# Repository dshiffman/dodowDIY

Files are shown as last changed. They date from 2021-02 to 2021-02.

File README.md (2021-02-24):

# dodowDIY
**An ATTiny85 implementation of the well known sleep aid. Includes circuit, software and 3d printed case design**  
The STL shells are desiged around parts I had hanging around - easy to remodel for different batteries, switches, etc.

Parts list:  
* ATTiny85 (I used a DIP8 version)  
* 8 pin socket  
* 47 ohm resistor  
* micro momentary push button switch  
* micro spst switch  
* 3x 5mm blue leds  
* CR17345 or DL123A battery
* battery terminals  
* Some proto-board (20mm wide if you want to use my STLs unaltered)

you'll also need a way to program the MCU (I used a Tiny Programmer)

That's it!

By-the-way, if everything is running 8 times too slow, it's probably because the 'low' fuse in your ATTiny is programmed to divide the clock by 8 (fuse - 0x62) to get the device to run at 8mhz, burn the low fuse to 0xE2 instead.

There's no on/off switch because at the end of the cycle the ATTiny is put to sleep and only draws a few micro-amps.  Given the 1.4 amp-hour capacity of the battery it will last for years.

A couple of folks have commented that blue LEDs aren't conducive for sleep - in the Dodow (https://www.mydodow.com/) FAQ they claim that "The color blue was chosen after much testing, based on the generally accepted perception that blue is calming. Blue light in high doses can help wake you up by inhibiting melatonin secretion, but Dodow does not. Being projected on the ceiling, the light signal, at its maximum intensity and for someone who is lying in bed, has a very low intensity". 

The faint glow on the ceiling fading in and out and gradually slowing down is actually quite soothing in my experience. To reduce the brightness of the LEDs you can always increase resistor value.

STL files, Source Files are in the obvious places.

The Pics folder has the assembly at various stages to give you an idea of the approach.

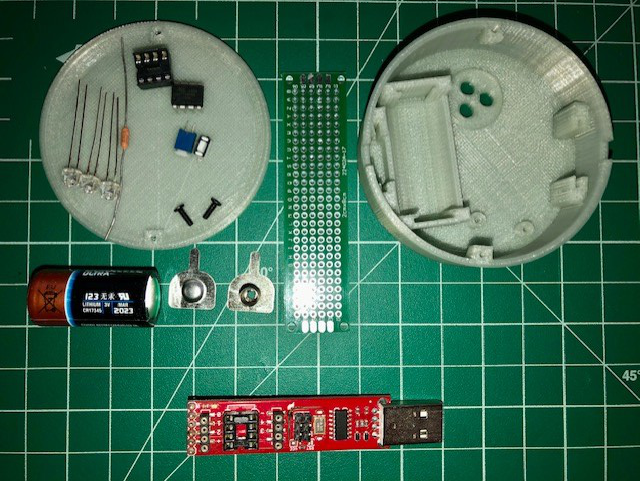
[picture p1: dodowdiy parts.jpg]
here are the parts I used


https://www.thingiverse.com/thing:4761399

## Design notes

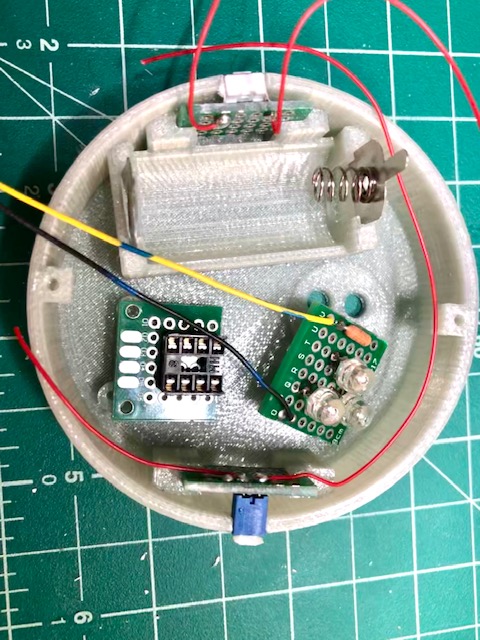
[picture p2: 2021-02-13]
pics/dodowdiy modules.jpg

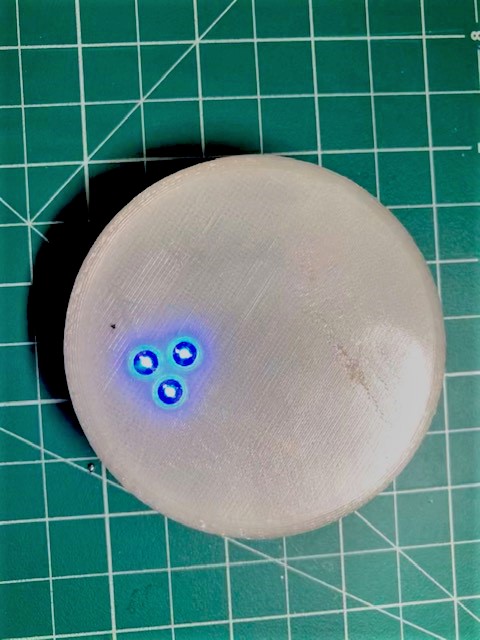
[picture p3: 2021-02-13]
pics/dodowdiy complete.jpg

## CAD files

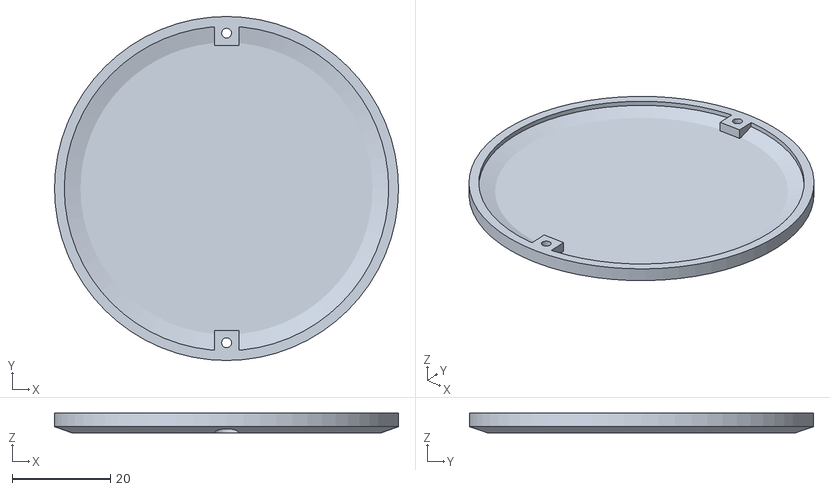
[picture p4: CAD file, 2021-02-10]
STLs/dodowdiybot.stl
70.0 x 70.0 x 4.00

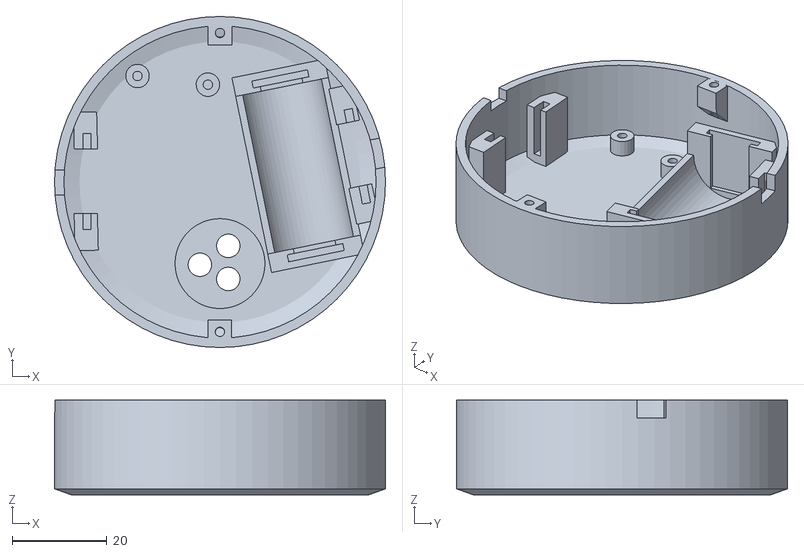
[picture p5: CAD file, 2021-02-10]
STLs/dodowdiytop.stl
70.0 x 70.0 x 20.0

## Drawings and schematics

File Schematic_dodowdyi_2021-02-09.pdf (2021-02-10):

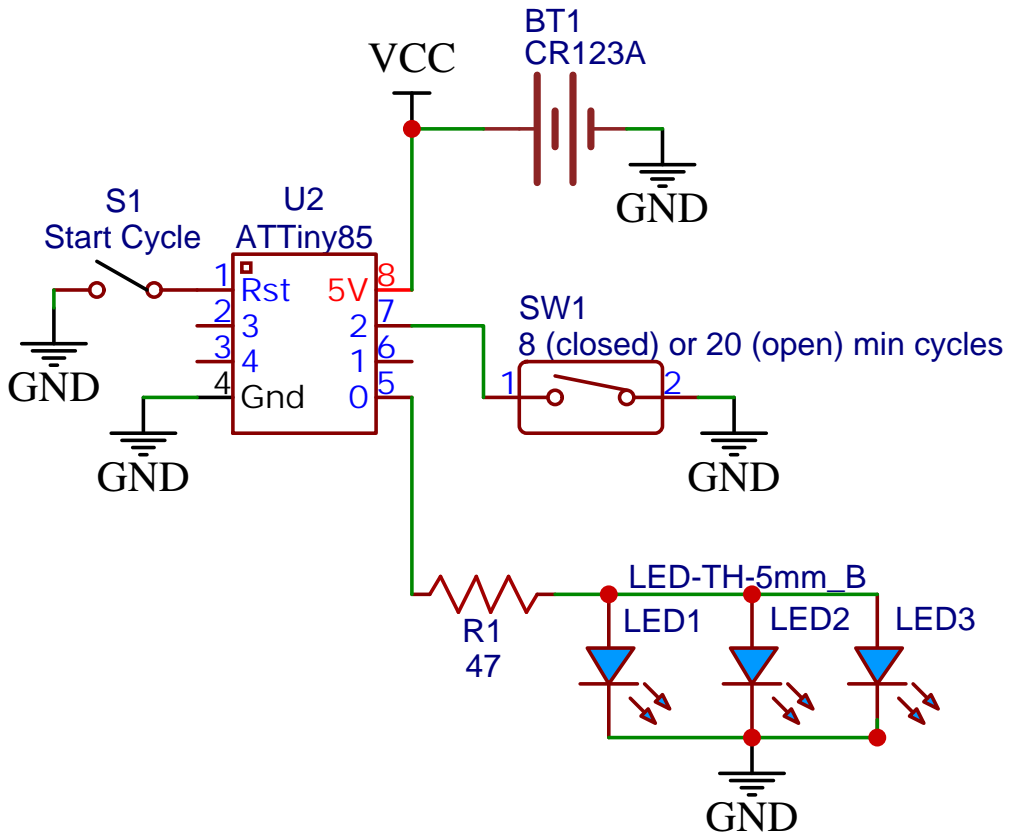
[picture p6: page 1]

8 (closed) or 20 (open) min cycles

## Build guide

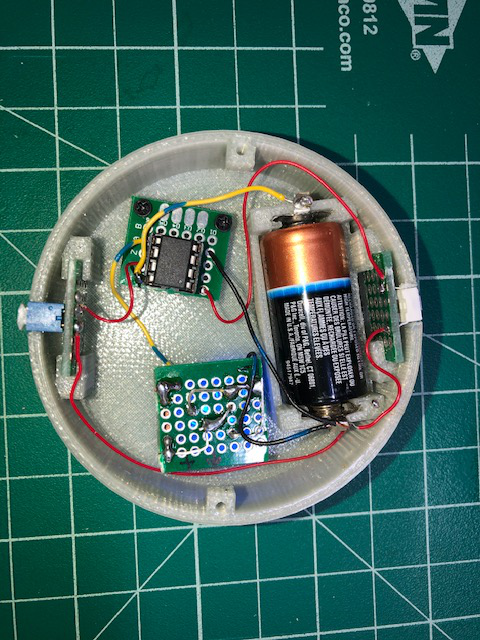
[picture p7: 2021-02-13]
pics/dodowdiy assembled.jpg

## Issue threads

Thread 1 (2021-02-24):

BLUE Leds "prevent" you from sleeping

chrisrock1984, 2021-02-24:
As you might know, blue leds are counterproductive when you want to sleep ;-)
Just a remark, not an issue.

BR

dshiffman, 2021-02-24:
Thanks Chris, this is a copy of the Dodow (https://www.mydodow.com/) and they claim in their FAQ that _"The color blue was chosen after much testing, based on the generally accepted perception that blue is calming. Blue light in high doses can help wake you up by inhibiting melatonin secretion, but Dodow does not. Being projected on the ceiling, the light signal, at its maximum intensity and for someone who is lying in bed, has a very low intensity"_ . The faint glow on the ceiling fading in and out and gradually slowing down is actually quite soothing in my experience.  I think the general statement about blue light is true for brighter sources not faint glows.

Closed 2021-02-24.

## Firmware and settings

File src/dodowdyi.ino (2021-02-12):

// Inspiration from gary909 instructable:
// https://www.instructables.com/DIY-Dodow-Clone-Arduino-Sleep-Meditation-Machine

#include "Arduino.h"
#include <EEPROM.h>
#include <avr/sleep.h>
#include "debug.h"

const int diag = PB1;           	// u/d indicator is attached  pin 6
const int led = PB0;           		// LED is attached to pwm pin 5
const int modeSwitch = PB2;			  // 8 or 20 on on pin 7
const int rx = PB3;
const int tx = PB4;
const float pwmIntervals = 254;
const float minpwm = 50;			    // minimum brightness
const float msPerMin = 60000;

diagPins(rx, tx);

// Fade a LED to perceived brightness rather than linearly
// Thanks to Diarmuid Mac Namara's blog for the calculation:
// https://diarmuid.ie/blog/pwm-exponential-led-fading-on-arduino-or-other-platforms
// Use lookup table in EEPROM rather than RAM, don't re-write each time

void populateLookup() {
	const float r = (pwmIntervals * log10(2))/(log10(255));
	diagPrintln ("Populate");
	byte PWMval, EEPval;
	for (int i = 0; i <= pwmIntervals; i++) {
		// Calculate the required PWM value for this interval step
		PWMval = round(pow (2, (i / r))) - 1;
		EEPval = EEPROM.read(i);
		if (EEPval != PWMval) EEPROM.write (i,PWMval); // Only write if changed
	}
}

void ramp (float BPM, float minutesDuration) {
	//40% in (up) 60% out (down) for total of 60,000/BPM milliseconds in up/down cycle
	unsigned int upmsdelay = round(0.4*msPerMin/BPM/(pwmIntervals-minpwm));
	unsigned int downmsdelay = round(0.6*msPerMin/BPM/(pwmIntervals-minpwm));
	byte reps = round(minutesDuration*BPM);
	byte brightness = 0;

	diagPrint (BPM,10);diagPrint (" breaths per min ");
	diagPrint ("for ");diagPrint (minutesDuration,10);diagPrintln (" min(s)");
	diagPrint ("up=");diagPrintln (upmsdelay);
	diagPrint ("down=");diagPrintln (downmsdelay);
	diagPrint ("reps=");diagPrintln (reps);

	unsigned long actual;
	unsigned long start = millis();

	for (int rep = 0;rep<reps;rep++) {
		digitalWrite (diag,HIGH);
		for (byte interval = (int)minpwm; interval <= (int)pwmIntervals; interval++) {
			brightness = EEPROM.read(interval);
			analogWrite(led, brightness);
			delay(upmsdelay);
		}
		digitalWrite (diag,LOW);
		for (byte interval = (int)pwmIntervals; interval > (int)minpwm; interval--) {
			brightness = EEPROM.read(interval);
			analogWrite(led, brightness);
			delay(downmsdelay);
		}
		diagPrint ("loop=");diagPrintln (rep,10);
	}

	actual = millis()-start;
	diagPrint ("each loop actual =");diagPrintln (actual/reps);
	diagPrintln ("---------");
}

void docycle () {
    diagPrintln ("DOCYCLE");
    int sensorVal = digitalRead(modeSwitch);

    //Check the switch to see if we sould run 8 or 20 mins
    if (sensorVal == LOW) {	//8 Min Structure
    	diagPrintln ("8 min loop");
    	ramp (11.0,1); 		//Min 1 = 11 breaths per minute
    	ramp (10.0,1);		//Min 2 = 10 breaths per minute
    	ramp (9.0,1);		//Min 3 = 9 breaths per minute
    	ramp (8.0,1);		//Min 4 = 8 breaths per minute
    	ramp (7.0,1);		//Min 5 = 7 breaths per minute
    	ramp (6.5,1);		//Min 6 = 6.5 breaths per minute
    	ramp (6.0,2);		//Min 7-8 = 6 breaths per minute
    } else { 				//20 Min Structure
       	diagPrintln ("20 min loop");
    	ramp (11.0,3); 		//Min 1-3 = 11 breaths per minute
    	ramp (10.0,3);		//Min 4-6 = 10 breaths per minute
    	ramp (9.0,3);		//Min 7-9 = 9 breaths per minute
    	ramp (8.0,3);		//Min 10-12 = 8 breaths per minute
    	ramp (7.0,3);		//Min 13-15 = 7 breaths per minute
    	ramp (6.5,2);		//Min 16-17 = 6.5 breaths per minute
    	ramp (6.0,3);		//Min 18-20 = 6 breaths per minute
    }
}


// the setup routine runs once powered on or when you press reset:
void setup() {
    diagBegin(9600);
    pinMode(diag, OUTPUT);
    pinMode(led, OUTPUT);
    pinMode(modeSwitch, INPUT_PULLUP);

    populateLookup(); //compute the fade values

    docycle(); //do it!

	/* Go into low power mode: -- thanks to Nick Gammon's blog: http://www.gammon.com.au/power
	 * All outputs to low
	 * ADC off
	 * Sleep mode to 'power down'
	 * Brown out disabled
	*/
    digitalWrite (diag,LOW);
    digitalWrite (led,LOW);
    digitalWrite (tx,LOW);
    ADCSRA = 0;
    set_sleep_mode (SLEEP_MODE_PWR_DOWN);
    sleep_enable();
    sleep_bod_disable();
    interrupts ();
    sleep_cpu ();
}

void loop() {
//never get here
}
